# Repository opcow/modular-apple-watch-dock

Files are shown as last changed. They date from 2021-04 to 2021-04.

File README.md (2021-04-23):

# Modular Apple Watch Dock / Charging Stand

There are versions of the bases that have holes for mounting feet or magnets on the bottom and versions with no holes. The holes were sized to fits some 3mm x 6mm neodymium magnets I have. The `foot-1.stl` part can also be pressed into the holes. If you don't want feet or magnets, or you want to use adhesive feet/pads of some sort then use the no-holes version.

Both versions of the claw have worked well for me. The jointed claw may be delicate. The jointed claw has a slightly larger gap where the cable should pass through. There is a mark (a small rounded slot) showing where the wire should go.

How to Print
---
Use whatever layer hieght you want. Infill as low as 10% has worked fine in my prototypes. I have printed all of the parts at 0.28 mm layer height and everything looked and printed fine. I print the charger mount thread side up, the base with its top side down.

You want good layer adhesion for the claw. I raised my usual print temperature a bit which made the claw less prone to breakage, but you want good cooling as well for the jointed claw so that the parts don’t fuse together too much. Some early iterations of the part were prone to breakage, but I've had no issues with the later ones, and I’ve printed quite a few. The claw is small and prints fast, in case you need to do a little trial and error or if you break it. I like to losen up the joints a bit before intalling the jointed claw, which I do by pressing inward near the joint. If you press in at the end of the finger then you are more likely to break break it.

---

There is a repo for this design on on my [Github](https://github.com/opcow?tab=repositories).

---
|Filename |Description | Required?  |
|---|---|---|
|`base-*.stl`|The dock base.|Yes.|
|`charger-mount.stl`|Holds the magnetic charger. The watch hangs here. |Yes.|
|`foot-1.stl`|A small foot for the base.|No.|
|`*-claw.stl`|Clamps the charger into the charger mount.|Yes.|
|`screw.stl`|Screws into the charger mount and operates the clamping mechanism.|Yes.|
|`modular-apple-watch-dock.step`|Step file contains 3D models for all of the above. No.|
|`README.md`|The documentation. |No.|

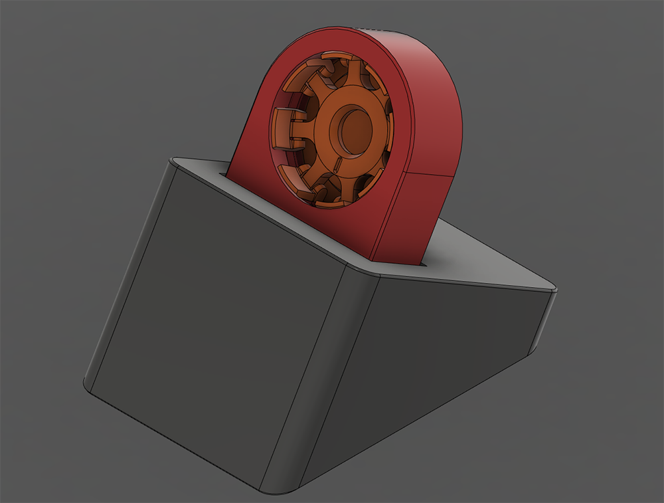
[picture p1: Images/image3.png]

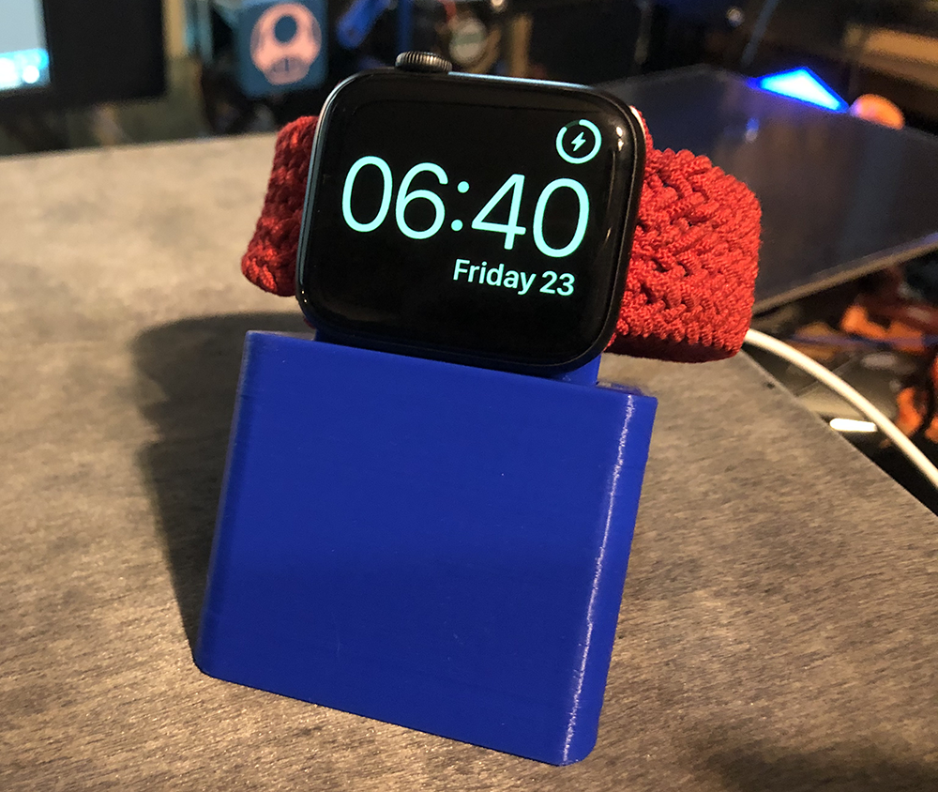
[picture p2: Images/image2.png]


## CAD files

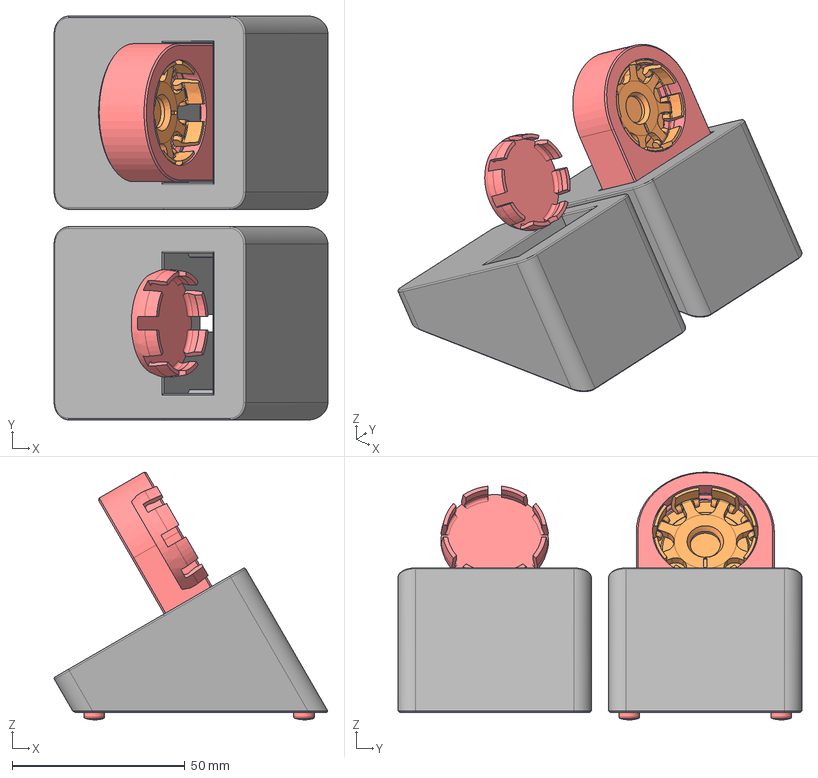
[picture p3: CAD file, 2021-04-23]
modular-apple-watch-dock.step
79.3 x 117.0 x 71.8 mm
base-holes
base-no-holes
charger-mount
jointed-claw
one-piece-claw
screw
feet

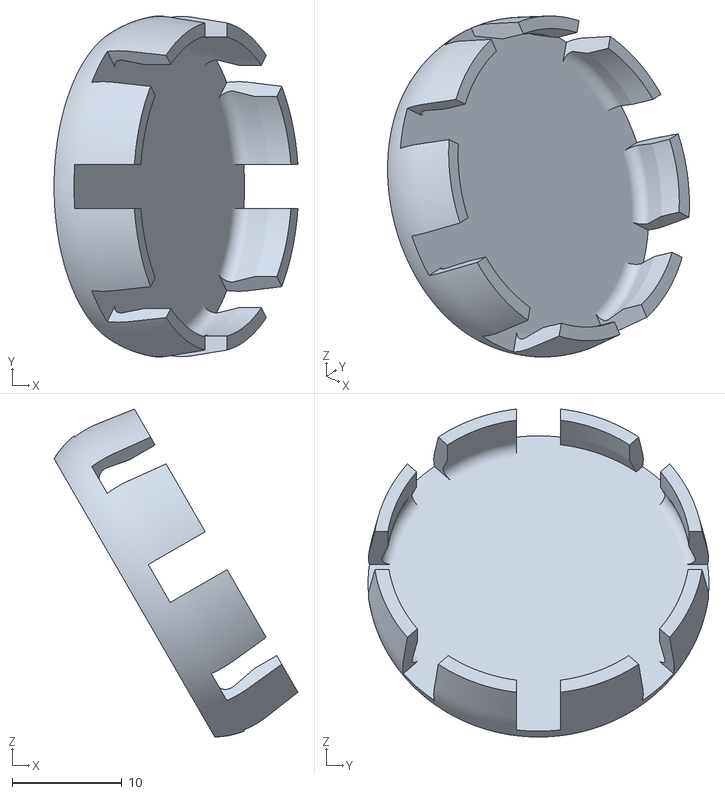
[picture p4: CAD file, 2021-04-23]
STL/one-piece-claw.stl
22.3 x 31.1 x 30.0

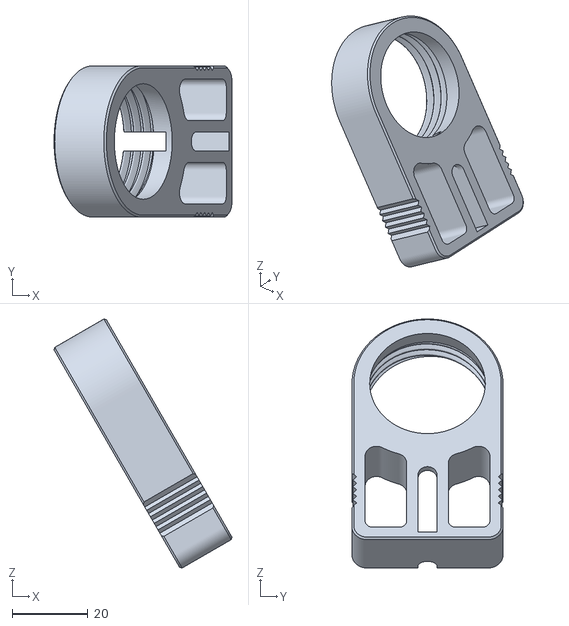
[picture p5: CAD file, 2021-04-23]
STL/charger-mount.stl
47.1 x 40.0 x 65.9

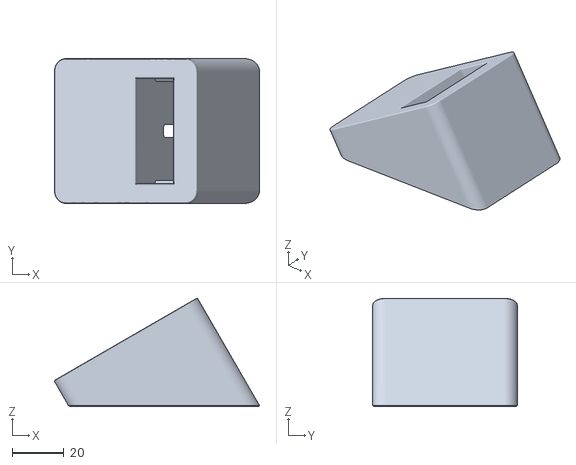
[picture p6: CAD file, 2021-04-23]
STL/base-no-holes.stl
79.3 x 56.0 x 41.9

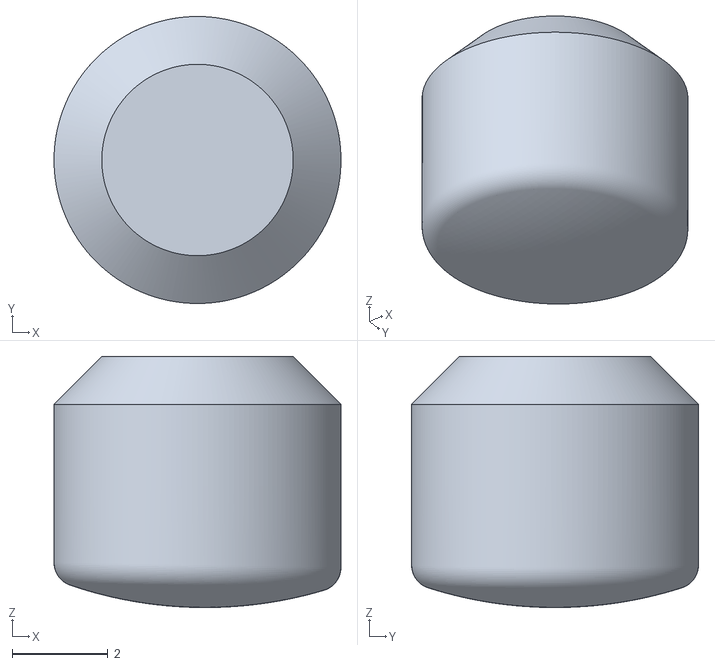
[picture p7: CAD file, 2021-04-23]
STL/foot-1.stl
6.00 x 6.00 x 5.25

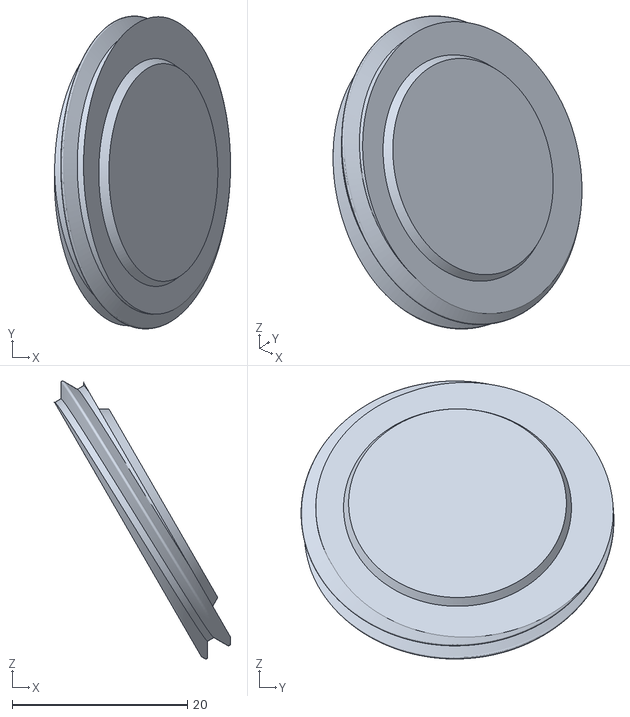
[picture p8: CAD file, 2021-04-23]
STL/screw.stl
20.1 x 35.7 x 31.7

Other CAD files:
STL/base-holes.stl

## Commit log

2021-04-10 add all the things
    [base-flared-holes.stl, base-flared-no-holes.stl, base-holes.stl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]
2021-04-10 Add optional seperated claw parts.
    [claw-finger.stl, claw-frame.stl]
2021-04-10 Fixed part name.
    [one-piece-claw.stl, one=piece-claw.stl]
2021-04-11 Added jointed claw version 2.
    [claw-2.stl]
2021-04-11 Beefier claw v2.
    [claw-2.stl]
2021-04-11 Claw v2 info.
2021-04-11 Tweak finger profile.
    [claw-2.stl]
2021-04-11 Tweak cradle size.
    [cradle-44mm.stl]
2021-04-11 Cradle tweaks and info.
    [cradle-44mm.stl, cradle.stl]
2021-04-11 Removed old jointed claw files.
    [claw-finger.stl, claw-frame.stl]
2021-04-13 Renamed in prep for V2 parts.
    [base-holes-v1.stl, base-no-holes-v1.stl, charger-mount-v1.stl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]
2021-04-13 Renamed in prep for V2.
    [base-holes.stl, base-no-holes.stl, charger-mount.stl]
2021-04-13 Renaming and reorganization.
    [claw-2.stl, front-plug.stl, front-press-in.stl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]
2021-04-13 Better fit.
    [cradle.stl]
2021-04-13 Version 2 parts.
    [base-holes-v2.stl, base-no-holes-v2.stl, charger-mount-v2.stl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]
2021-04-13 Updated? *shrug*
    [one-piece-claw.stl]
2021-04-13 Renaming / reoganization.
    [front-slot-cover.stl, front-wire-cap.stl, jointed-claw.stl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]
2021-04-13 Added shim for V2.
    [shim.stl]
2021-04-13 Resize shim.
    [modular-apple-watch-dock.step, shim.stl]
2021-04-14 Renaming with version.
    [rear-slot-cover.stl, rear-wire-cap.stl, wire-cap-plate.stl]
2021-04-14 Ignore STL of entire assembly.
2021-04-14 Identical slots between V1 and V2.
    [front-slot-cover.stl, front-wire-cap.stl, modular-apple-watch-dock.step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]
2021-04-14 Removed reference to renaled STL.
2021-04-14 Some parts were hidden.
    [modular-apple-watch-dock.step]
2021-04-14 Move STLs to subdir.
    [base-holes-v1.stl, base-holes-v2.stl, base-no-holes-v1.stl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]
2021-04-15 New mini dock.
    [base-mini.stl, clamp-mini.stl]
2021-04-15 Printing info. New file names.
2021-04-15 More reorg. Added mini dock.
    [base-holes-v1.stl, base-holes-v2.stl, base-no-holes-v1.stl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]
2021-04-15 Removed front slots and related parts.
    [base-holes-v1.stl, base-holes-v2.stl, base-mini.stl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]
2021-04-15 No more front slots. No need for rear cover.
    [rear-slot-cover.stl]
2021-04-17 Tweaks to sizing of parts.
    [clamp-mini.stl]
2021-04-17 No longer used.
    [wire-cap-plate-v1.stl]
2021-04-17 Slot redesign to hold the wire in place.
    [base-holes-v1.stl, base-holes-v2.stl, base-mini.stl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]
2021-04-17 New slots, redesigned mini.
2021-04-17 Chamfer the meni clamp for more clicky feel.
    [clamp-mini.stl, modular-apple-watch-dock.step]
2021-04-17 Move mini dock to its own project.
    [base-mini.stl, clamp-mini.stl, modular-apple-watch-dock.step]
2021-04-19 Removed slots next to the wire pass-thru.
    [base-holes-v1.stl, base-holes-v2.stl, base-no-holes-v1.stl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]
2021-04-23 Removed versions 1 and 2.
    [base-holes-v1.stl, base-holes-v2.stl, base-no-holes-v1.stl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]
2021-04-23 Third revision. No screws required.
    [base-holes.stl, base-no-holes.stl, charger-mount.stl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]
2021-04-23 Accidentally removed.
    [one-piece-claw.stl]
2021-04-23 Updated for rev. 3.
    [modular-apple-watch-dock.step]
